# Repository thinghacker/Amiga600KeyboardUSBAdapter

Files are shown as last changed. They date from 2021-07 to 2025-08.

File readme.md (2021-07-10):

# Amiga600 Keyboard USB Adapter
This project enables an existing Amiga 600 Keyboard to operate as a USB Keyboard with the Case LEDs to indicate power/scroll lock and numlock.
This is a reimplementation of my previous [Teensy 2.0++ based PCB](https://github.com/thinghacker/amiga600_usb_pcb) and [QMK Firmware](https://github.com/thinghacker/qmk_firmware/tree/amiga600/keyboards/amiga600) adapter however as the Teensy 2.0++ is approaching end of sales availability and is relatively expensive,
this recreation uses the Raspberry Pi Pico in combination with a MCP20008 IO Expander for the keyboard interface and the keyboard driver software written in [CircuitPython](https://circuitpython.org/)

The [Kicad](https://www.kicad.org/) files used to create the PCB are in the [PCB-Amiga600Keyboard_USB_Pico](PCB-Amiga600Keyboard_USB_Pico/) directory - generated gerbers are the **plot** directory
The CircuitPython code is in the [CircuitPythonCode-Amiga600Keyboard_USB_Pico](CircuitPythonCode-Amiga600Keyboard_USB_Pico/) directory

Please note that the code requires the following libraries in addition to the base CircuitPython Install 
* [Adafruit_CircuitPython_HID](https://github.com/adafruit/Adafruit_CircuitPython_HID)
* [Adafruit_CircuitPython_MCP230xx](https://github.com/adafruit/Adafruit_CircuitPython_MCP230xx)

### Bill of Materials

|Designation | Item | Description | Manufacturer|
| --- | --- |--- | --- |
| U1 | Raspberry Pi Pico | RP2040 Board with USB Connector | https://www.raspberrypi.org/products/raspberry-pi-pico/ | 
| U2 | MCP20008 | 8 bit I2C IO Expander | https://www.microchip.com/wwwproducts/en/MCP23008 | 
|J1|4 Pin Header Right Angle PCB Mount 2.54mm spacing|Connects to Amiga 600 Case LEDs|Sullins Connector Solutions SWR25X-NRTC-S04-RB-BA available from Jaycar as HM3424|
|J2|30 Pin FPC Connector 1.25mm spacing| Connects to the Amiga 600 Keyboard Ribbon|Molex 39532304|
|R1 & R2 |4K7 Ohm Resistor|Pullups for I2C|various|

### PCB
This is a fairly simple two layer through hole design.  There are holes in the PCB to accomodate 3mm Nylon standoffs, self-adhesive types mean you can attach it to the back of the keyboard if desired.

Assembled Prototype PCB
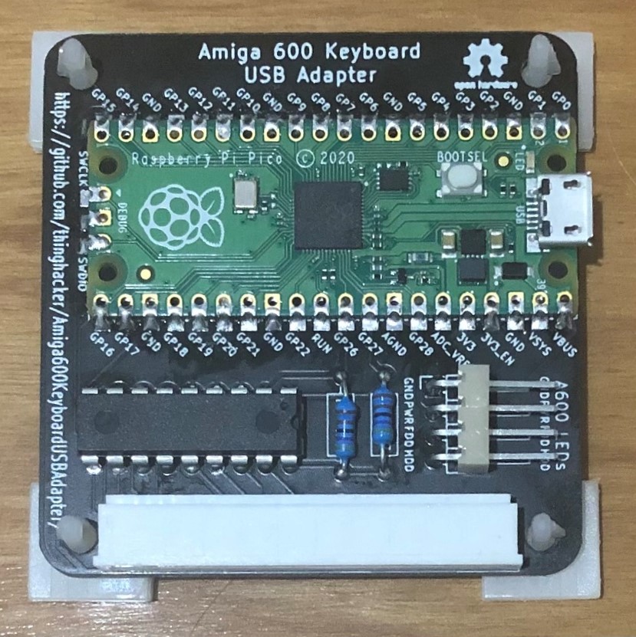
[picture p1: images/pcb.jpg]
Assembled Prototype PCB Image


Assembled Prototype PCB connected to a Keyboard
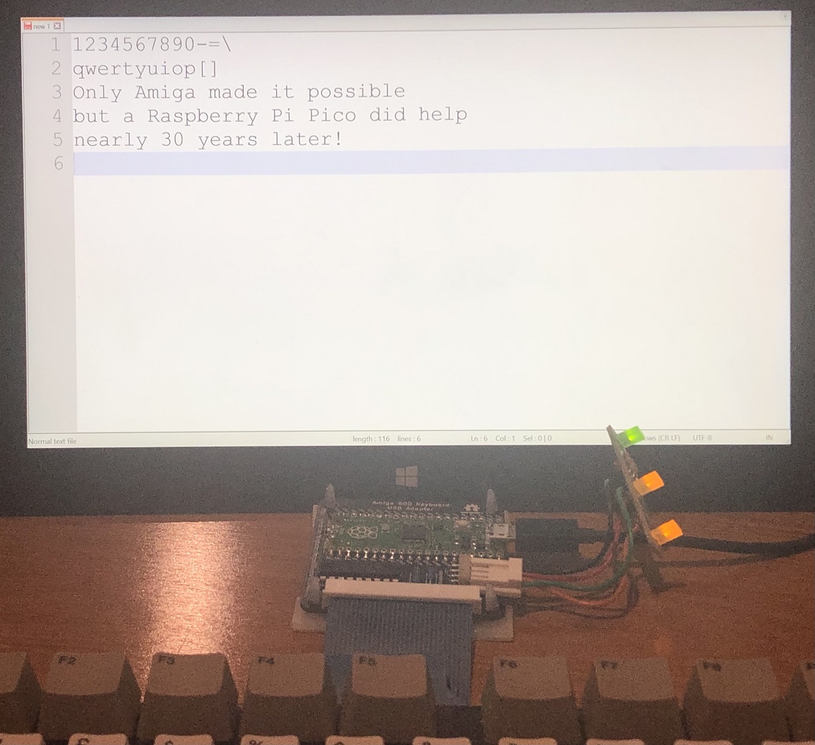
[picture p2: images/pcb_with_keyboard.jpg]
Assembled Prototype PCB Image


### Construction Notes
This PCB does not require any advanced soldering skills, it may be best to work with an experienced friend or watch some youtube videos on build techniques if you don't feel confident.

The hardware and software as written by me is distributed under a GPL Version 3 License

No claims to the name or any trademarks associated with Amiga, Raspberry Pi, Pico or Tim Tam are asserted here.

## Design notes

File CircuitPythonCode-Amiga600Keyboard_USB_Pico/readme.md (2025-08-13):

# Amiga600 Keyboard USB Adapter CircuitPython Firmware
This project enables an existing Amiga 600 Keyboard to be USB enabled via a Raspberry Pi Pico and MCP20008.

Keyboard Maintainer:  https://github.com/thinghacker

Supported Hardware: [Amiga 600 USB Keyboard Adapter](https://github.com/thinghacker/Amiga600KeyboardUSBAdapter/tree/main/PCB-Amiga600Keyboard_USB_Pico)

### Features

- Uses CircuitPython and two Adafruit Libraries
- Uses the Amiga 600 case LEDs for Power / Number Lock (FDD) and Scroll Lock (HDD)
- For the English keyboard variant, the two blank "International" keys shift layers to support more contemporary functions such as F11, F12, Numeric Keypad and Media Keys
- [Uses a simple PCB Design](https://github.com/thinghacker/Amiga600KeyboardUSBAdapter/tree/main/PCB-Amiga600Keyboard_USB_Pico) with a small number of components

### Build Instructions
- Construct the PCB and connect it to the USB port of your computer where the Pi Pico should appear as a USB flash drive
- Download the **uf2** file from [install CircuitPython](https://circuitpython.org/board/raspberry_pi_pico/) and copy it to your Pico Pico (this code was written using version 6.3.0)
- Copy the CircuitPython HID library [Adafruit_CircuitPython_HID](https://github.com/adafruit/Adafruit_CircuitPython_HID) (adafruit_hid directory) to the **lib** directory on your Pi Pico
- Copy the CircuitPython mcp230xx library [Adafruit_CircuitPython_MCP230xx](https://github.com/adafruit/Adafruit_CircuitPython_MCP230xx) (adafruit_mcp230xx directory) to the **lib** directory on your Pi Pico
- Copy the code.py file from this repo to your Pi Pico
- Remove the USB cable, attach the keyboard and LEDs to the Adapter
- Reattach the USB cable and type away!

### Keyboard Layer Configuration

#### Base Layer
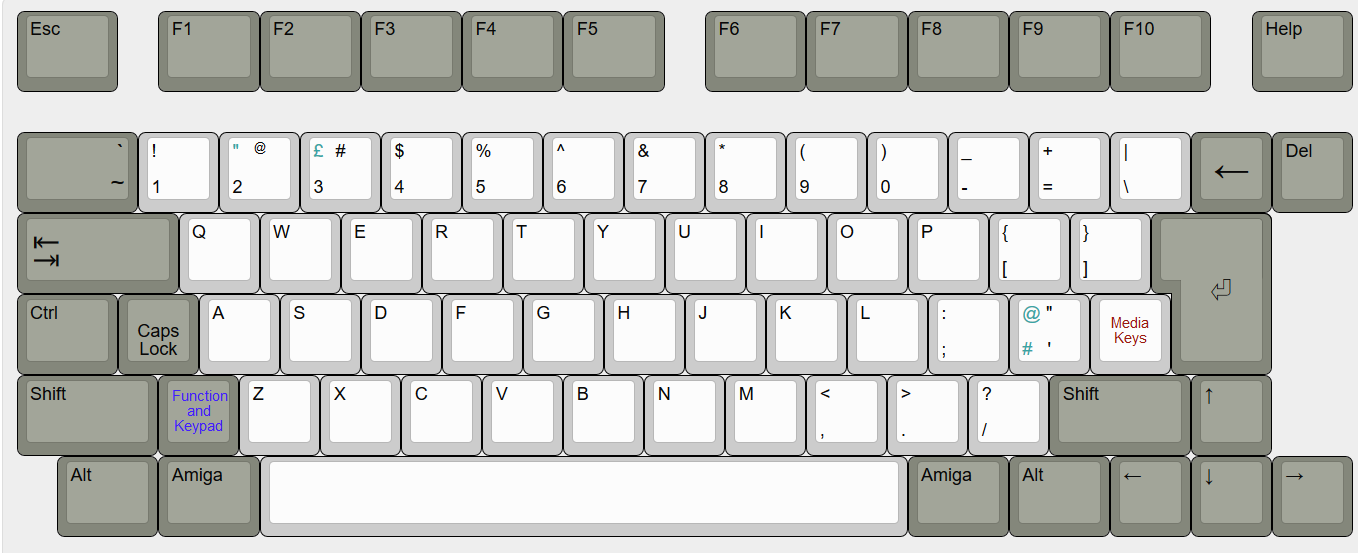
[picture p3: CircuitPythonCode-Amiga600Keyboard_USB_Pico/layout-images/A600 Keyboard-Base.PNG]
Base Layer


- My particular keyboard is the UK variant (differences are shown as Green on the keys), however this keymap is configured as if it was USA.
- The Left "Blank" Key (immediately to the right of left shift) is used to enable the Additional Function Keys and Numeric Keypad Layer
- The Right "Blank" Key (above right shift) is used to enable the Media Keys Layer

#### Additional Function Keys and Numeric Keypad Layer
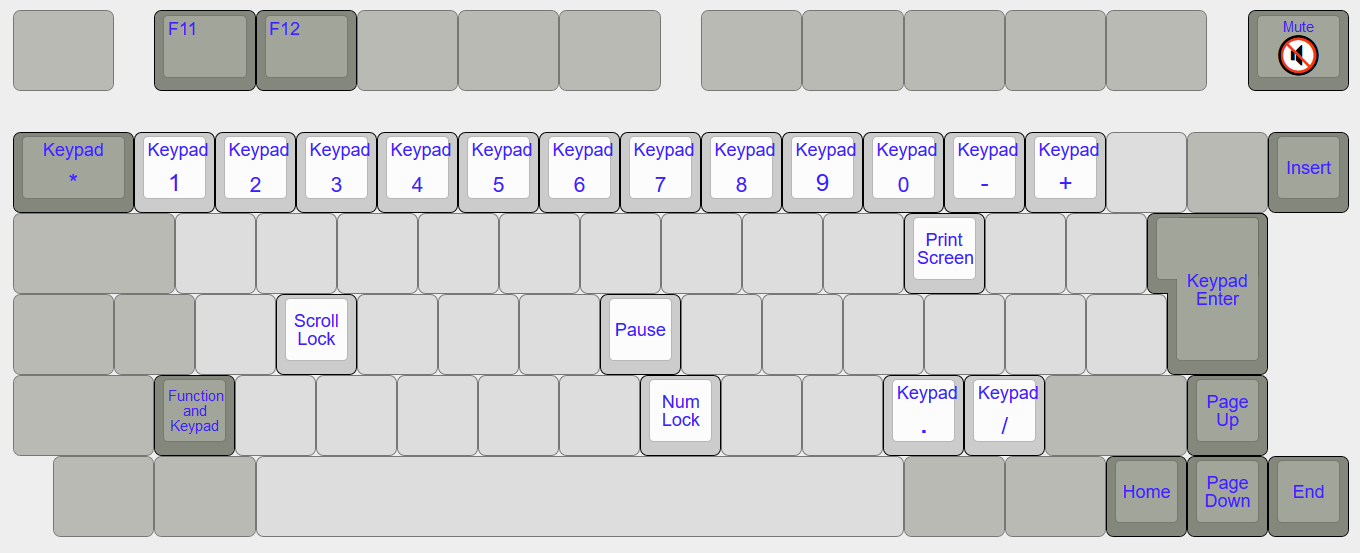
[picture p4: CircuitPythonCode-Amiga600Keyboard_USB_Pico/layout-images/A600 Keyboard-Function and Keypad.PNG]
Additional Function Keys and Numeric Keypad Layer


#### Media Keys Layer
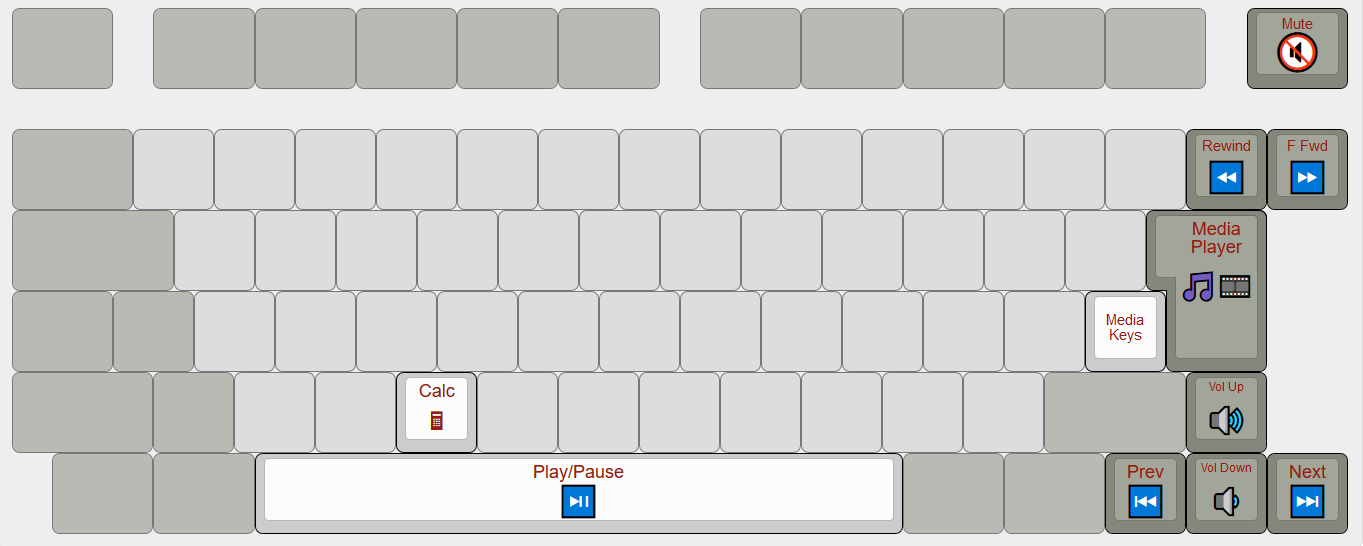
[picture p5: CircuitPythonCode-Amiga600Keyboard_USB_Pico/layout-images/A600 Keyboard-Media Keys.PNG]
Media Keys Layer


This is broadly inspired but very much a poor mans representation of the amazing [QMK firmware](https://github.com/qmk/qmk_firmware) that is extremely limited in scope and capability but seems good enough for me.

The software as written is distributed under a GPL Version 3 License

#### Update 14-Aug-2025
This project has not been actively maintained for some time, however thanks to [n0rt0nthec4t](https://github.com/n0rt0nthec4t) and [Amellinium](https://github.com/Amellinium) an [issue](https://github.com/thinghacker/Amiga600KeyboardUSBAdapter/issues/4) with regards to needing to remove and re-insert the keyboard has been addressed, thank you both for your help.

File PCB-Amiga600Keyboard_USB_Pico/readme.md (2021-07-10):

# Amiga600 Keyboard USB Adapter Using a Raspberry Pi Pico and MCP20008
This Kicad 5.1.10 project enables an existing Amiga 600 Keyboard to be USB enabled via a Raspberry Pi Pico and MCP20008 with the appropriate firmware such as [This CircuitPython Firmware](https://github.com/thinghacker/Amiga600KeyboardUSBAdapter/tree/main/CircuitPythonCode-Amiga600Keyboard_USB_Pico)

The hardware design open and distributed under a GPL Version 3 License

[Here is a PDF of the schematic for reference](schematic.pdf)

Gerbers have already been generated and are present in the "plot" directory

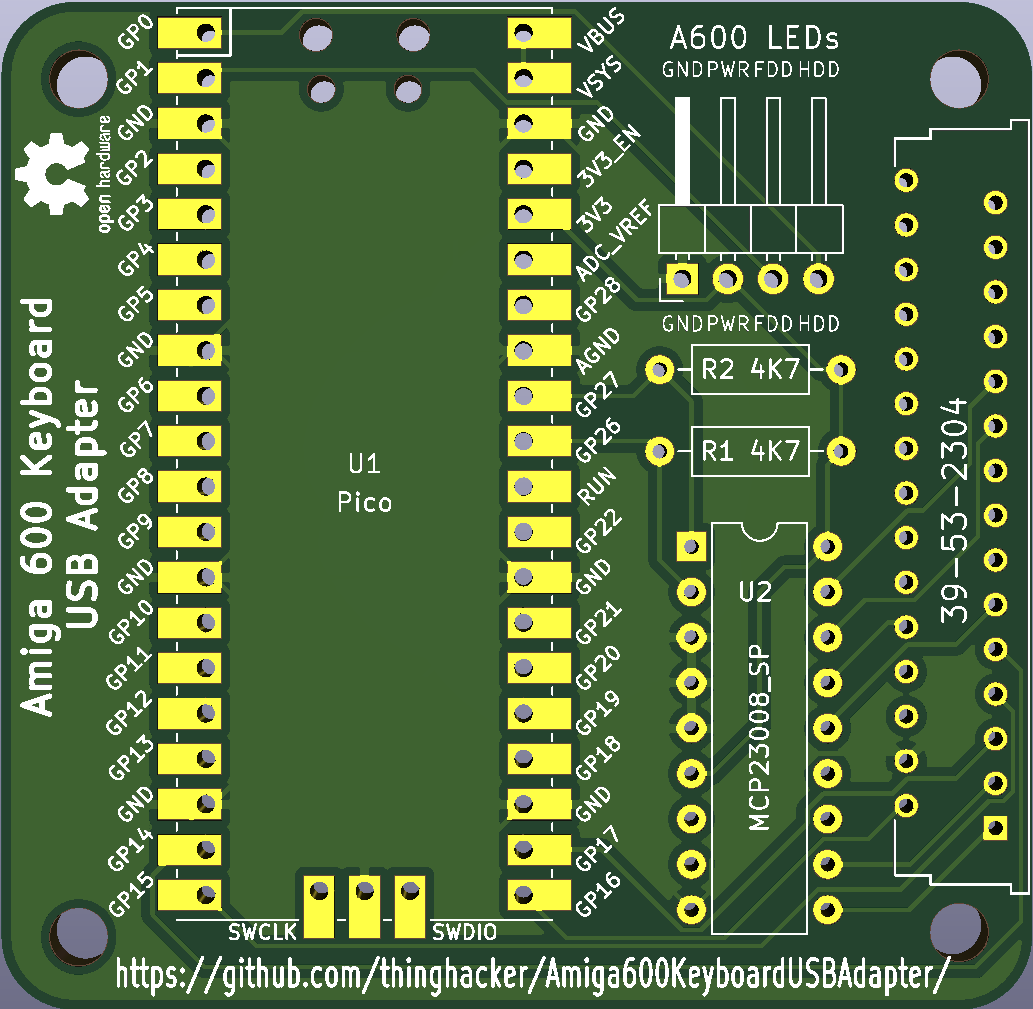
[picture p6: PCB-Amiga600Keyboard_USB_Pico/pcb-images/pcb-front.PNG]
PCB Front


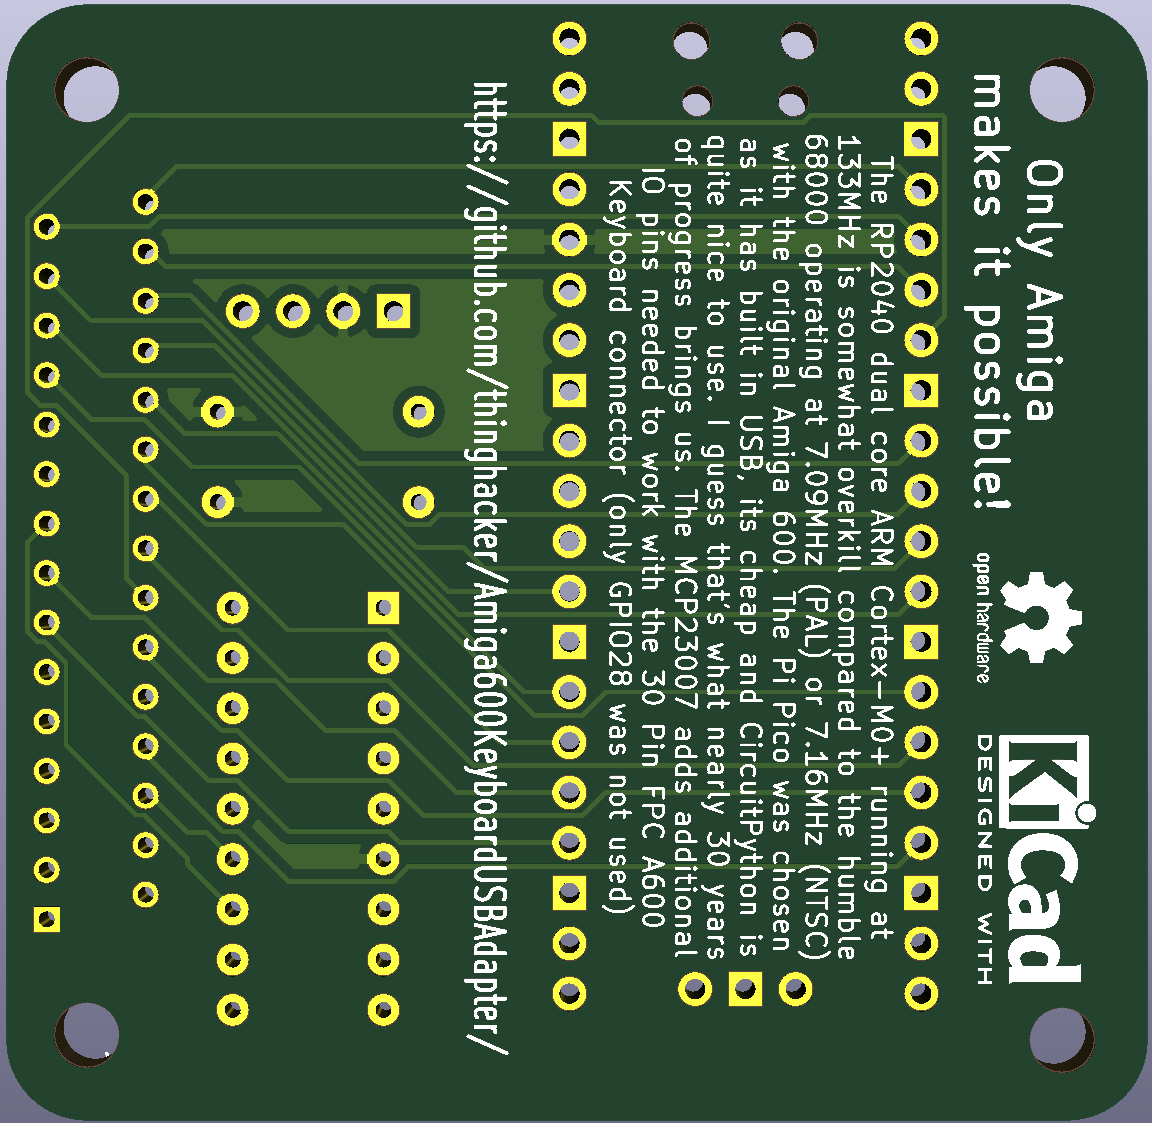
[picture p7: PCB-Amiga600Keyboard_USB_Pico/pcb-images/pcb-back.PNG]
PCB Back


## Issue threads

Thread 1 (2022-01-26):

Some suggestions for future improvements

OleUrgast, 2022-01-26:
Hello,

thanks for your great work.

I just got some mechanical keyboard PCBs (designed by Adam Eberbach [(aerberbach here on github](https://github.com/aeberbach/A600KB)) for the A600 from pcbway, as I want do make an Amiga emulator (Rasperry Pi, mechanical keyboard, DrawBridge with floppy, Slot-In CD-Drive).

Also I thought about how to make a keyboard controller and ordered some parts (Arduino Nano and CD74HC154EN). Than I found your project.

While I like your project a lot, I have a few questions:

- You use the two „blank“ keys for extra functions. As I am German, the two keycaps are not blank. How hard is it to change the function back to original keycode?

- I actually like extra keys. In the keyboard matrix the crosspoints 1/16, 1/22 and 1/24 are not used (the row with the function keys). I consider to glue the 3 LEDs onto little switches and let the LEDs become extra buttons, and wire them to 1/16, 1/22 and 1/24. So the look of the A600 does not change even with this „extra“ keys. How hard would it be to implement theese extra keys on 1/16, 1/22 and 1/24 into firmware?

Some suggestions:

You use nearly all of the I/Os of the Pi Pico + one extender IC. It seems a bit wastefull to me to use so much I/Os of the Pico, as only one colum of the Matrix is used at a time. As I thought about an own solution, I thought about a 4:16 decoder (CD74HC154EN). This Chip is quite simple: you connect it to 4 IO-Ports of the microcontroller, connect both enable inputs permanently to low. The 4 inputs are the „adress“ wich output is to be set to low. So if you set the 4 IOs to 0000, output 0 goes low, 0001, output 1 goes low,..., 1111 output 15 goes low. Always the other outputs are high.
So you can adress all 15 colums of the main keyboard matrix.
Also the reason for a seperate matrix for modifier only is anti-ghosting. Using a second 4:16 decoder (or a 3:8 one) on the same IOs would not result in ghosting, as the outputs still are seperated. So you can connect both 4:16 decoders to the same 4 I/Os. So for all the 22 colums you only need 4 I/Os of the Pico.

Only for the 6 rows (5 main matrix, 1 modifier matrix) you need one I/O per row to read wich key is pressed
So with 10 I/Os on the microcontroller you can actually read the complete keyboard (+1 I/O to light up caps-lock).
This gives you a lot of free I/Os on the Pi Pico and would allow aditional features.

Suggestions for additional features:

a) Joystick port. Actually Kerath v2 maps joysticks to the keymap. There are two methods most emulators support. Individual Computers (icomp.com) describes them on their website http://wiki.icomp.de/wiki/Keyrah_V2#Joystick_mapping.

b) A1200 keyboard support (extra 31 or 32 pin FCC connector (like used on aeberbachs A1200 mechanical keyboard))

c) Jumpers.
- Change configuration between maping extra functions to blank keys or send original keycode (international users) (mapping to 1/16, 1/22 and 1/24 can be always active in parallel, it does not hurt)
- Change between A600 and A1200 keyboard

d) extra output: Clock + Data for Amiga 1000/500/2000/3000/4000/CDTV/CD32 - so you can use your A600 Keyboard as an external keyboard for theese. Esp. if you add support for A1200 keyboards, this would allow mechanical keyboards using aeberbachs mechanical keyboards with your controller inside the original (keyboard-)case (exept on the A1000 of course). Of course level shifter is to be added due to Amiga using 5V

e) extra 4-pin connector for lines 1,16,22,24 to connect an external 3-key „keyboard“ (LEDs mounted on switches or extra keys hidden on the back of the Amiga case)

Just some ideas for further improvements in the future.

As I neither have skils in KiCad nor Python programing, I do not now if theese suggestions are possible to do or how hard it would be to implement them.

OleUrgast, 2022-02-01:
Actually even without Python knowlage your well written code seems to be easy to adapt to my needs.

For getting the international keycodes I found only "KEYPAD_BACKSLASH" wich should be one of the two blank keys on us-keyboards so far (it is marked "(non-us)" on https://circuitpython.readthedocs.io/projects/hid/en/latest/api.html ). I still not know the keycode for the other key, but as a full size keyboard US is 104 keys and ISO 105 keys the other key should exist in US layout also, so I will find it by trial and error. So I am pretty sure I only have to change KC.LAYERSHIFT_1 and KC.LAYERSHIFT_2 in KEYMAP_M1[0] to "KEYPAD_BACKSLASH" and the other code I still have to find out.

Also extra keys for function layer for international users are not needed, as there is a key most users do not like and deactivate anyway: Caps Lock. >95% the time Caps Lock is active, it was by accident. It is a relict from typewriters were the only way to emphesice something was to use capitals or underline a text. I know no one actual using capslock, even retro fans. There are people who deactivate it anyways, if they can. So all to get a function key for international users would be changing KC.CAPS_LOCK to KC.LAYERSHIFT_1 in KEYMAP_M1[0] if I understand correctly.

Even joystick emulation should be no problem, as there is still one free pin on the Pico (GPIO 28). So add it as an extra row after line 148 "digitalio.DigitalInOut(board.GP28)", connect it to the gnd pin of 9 pin d-sub sockets and wire pins 15,17,19,21,23 and 25 to up, down, left, right, fire1, fire2 of first joystick connector and pin 16,18,20,22,24 and 26 to up, down, left, right, fire1, fire2 of second joystick connector. Than add a line to KEYMAP_M1[...], so the coresponding numpad keycodes for emulators are send if joystick is used.

Practicly the 5/6 switches in a joystick are treated as extra keys (numpad keys) in a seperate row.

Of course this way only passive joysticks are supported, as we do not have real "ground" and neverever 5V for autofire joysticks (at least without using extra hardware). But autofire is cheating anyway and using some good old competition pro would definitly be a benefit.

All this should work without modifying the PCB, as the colums are easy to access at the back side of the PCB at the ribbon connector. Using every second pin means it is easy to solder standard pitch 2.54 pins (1*7, one not soldered to the connector but bend up and batchwired to GPIO28) to the back of the flat cable connector.

As soon as my PCBs arrive and get the controller board ready, I will definitly try this hack and report. If it works out as I think, you might add it into regular firmware, as adding a row to the matrix would'nt effect normal use at all. But maybe in future revisions of your board you might add two headers 1*7 (or even better: two 2*5 with one pin removed, to directly plug a db9 cable as used in older computers for serial conectors on a slot bracket. Would be nice to reuse theese old parts for joystick ports...)

thinghacker, 2022-02-01:
Hi, sorry for the delayed response but it is great that you are able to look at this and extend things to your liking, please let us know how it goes.

Regarding the keymapping - certainly the idea was that it should be possible adapt things to your own desires, for non-UK/US keyboards it should be possible modify things are necessary - in part I suspect it depends on how things are intended, if I understand https://usb.org/sites/default/files/hut1_21_0.pdf#page=83 correctly some of the changes should be transparent to a degree as the local USB host would determine the right re-mapping operation.
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
OleUrgast, 2022-02-12:
I made some progress - Not for the controller, as I still wait for the PCBs, but for the mechanical keyboard and the keycaps.

As I have a lot of plate-mounted switches flying around I got into problems to align them on the PCB. Without the two extra plasitic pins the 5-pin keys have, it is hard to solder them straight.
So I designed a mounting plate for the A600kb PCB. It also has holes to mount standard  chery-style stabilzers; as the keycap generator I use always place the mounting points same as on an 6.25u spacebars even if you make an 8.25u spacebar, this is quite usefull.

I added two photos, one from my first try with plate printed in two parts in my mk3s, the other improved one (more stiffness) printed on an Anycubic Predator in one piece.

Also I printed a (nearly) complete set of OEM Style keycaps. Only ISO-Enter in OEM Profile I am still looking for. As I am still learning how to print with resin, not all keycaps are perfect yet. But the last keycaps worked out quite well.
For the test I used green transparent resin, just because I got two liter with the printer. Sadly the A600kb from Adam has no backlightning, else I would bei tempted to use it for a Final Version (but using red transparent resin for the gray keycaps...). But maybe later I might do a version with handwired LEDs ...
I already have white and gray resin, but before using this, I will do some improvement on the spacebar, functionkeys and hopefully find an ISO-OEM enter. Also I will test dyesubbing in Resin first.

I will publish the mounting plate as soon as I fixed some minor issues in thingiverse. As I do not have an original Amiga 600 I so not know what changes might be needed to mount the keyboard with the plate inside.

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

OleUrgast, 2022-02-23:
Some progress:
- yesterday the PCBs for the controller arrived, so I will start my experiments this weekend
- Also reprinted some keycaps with 0.01mm layerhight. Great look, I also improved washing (prewasch in 1st tank, 10 min in wash&cure in a 2nd tank, and 20min in a 3d tank)
- I tryed finesanding (1000+2500+5000 paper) and polishing keycaps. Only the top, not the sides. It looks fantastic, but at the moment I need at least 5 minutes per normal key (about 25 min. if doing it on the sides also. Definitly nothing you want do for every keycap...). So a lot of work to do.
- tryed DyeSub for printing on keycaps. While I just improvised on tools (I used a simple iRon(TM)) and also I could only try with some old testprints (the waste ink container of the printer is full) on normal paper (not transfer paper) I saved from the bin, I can definitly tell: it works. The resin withstands the 200°C for the time needed. Just make sure to be careful with preasure (I cracked one key). On the green resin (it is more green and darker than on the picture) the contrast is less than optimal, esp. when keycap is polished. But as it definitly works, I will build a special tool to transfer on keycaps. On white and light gray resin keycaps it should definitly be a perfect solution to make cherry compatible Amiga 600 keycaps.
- I also made a Mechboard64 now. So I will try to adapt your controler for the 64keyboard also.
- Also I ordered the A1200kb (beside CapsLock LED being on the bottom instead of the top).
- As CapsLock will be used as FN, I think I will simply change Ctrl to become CapsLock in second layer. So CapsLock-Key + CTRL-Key pressed together will activate/deactivate CapsLock.

thinghacker, 2022-02-23:
Wow @OleUrgast , you have been making really good progress here,  Thanks again for keeping us updated with what you have been doing.

I am interested in your key printing technique, and from what I can see with your keycaps - it seems quite impressive and makes me want get a resin printer myself.

Nice work!

thinghacker, 2022-02-28:
@OleUrgast, you have started to inspire me to revisit this project,  I suspect the introduction of a 31pin connector to support Amiga 1200 keyboards as well as A600 would be pretty straight forward from a hardware standpoint (and the difference would mainly be the associated keymatrix), however I have been thinking a bit about legacy DB9 joystick/mouse connectivity you mentioned awhile back and have put something together as a starting point to understand creating gamepads using the Pi Pico - https://github.com/thinghacker/PiPicoUSBSegaController.

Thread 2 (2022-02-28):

Debug GND pin

bjorn-felle, 2022-02-28:
Thank you for this project :) I hope it's ok to post this question as an issue here. I'd like to build this using a Pi Pico breakout board so I can have the Pico socketed and use screw terminals to connect other components. None of the prefab breakout boards I have found have the debug pins connected. Is it essential to have the debug GND pin connected? I could solder on to this pin and then connect this on the breakout board to one of the GND screw terminals if necessary but I'd rather not modify the Pico unless it's absolutely necessary

thinghacker, 2022-02-28:
Hi, the front side of the PCB has a filled zone of which the ground pins (including the debug ground) is attached, so there should be requirement to connect this in your case.

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

bjorn-felle, 2022-02-28:
Thank you, that makes sense. I'll solder a wire to that pin on the Pico and then connect it to one of the spare GND pins on the screw terminal board. Thank you again, I'm excited to make this part of my A600 case mod :)

thinghacker, 2022-03-01:
@bjorn-felle - this is a bit embarrassing but I didn't include the NOT part in my response - you can leave the GND pin associated with debug free.  Sorry for the confusion, I hope this helps you with your mod.  The A600 seems to miss out on a lot of the love other Amigas tend to get!

bjorn-felle, 2022-03-01:
That's ok, I appreciate the replies! Just to be sure we're not at crossed purposes, I'm not going to make the PCB but will be breadboarding the circuit. So in this case I just leave the debug GND pin hanging and not connected to anything is that right? Sorry if this is the wrong place to discuss this by the way.

thinghacker, 2022-03-06:
Maybe you have already built it now but no, you do not need to connect the debug ground pin here

Closed 2022-03-01.

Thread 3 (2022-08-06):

Wrong behaviour

ingloriond, 2022-08-06:
579 / 5.000
First of all, thank you for this fantastic project. When I finished mounting the PCB and programming the picopi I connected it to the pc and it worked correctly with wordpad. However, after 1 minute a key started to stay pressed... the letter that remains pressed changes. I thought maybe there was some flaw in the welds or even the picopi. Mount another new PCB, just only reuse the 8-bit I2C IO expander. The result has been the same... It works and after a short time it starts writing by itself. The keyboard works fine on an A600
Any suggestion?
Thank you

thinghacker, 2022-08-23:
Sorry for the delayed response. My keyboard/circuit is in storage at the moment but I will aim to bring it out and re-run things to see if I can replicate the condition you describe and track it from there.

As a matter of interest, is it the same key that is appearing to stay in a down state each time or is it different?  When the condition occurs - if you unplug the USB and re-insert it, do things work normally again?  If not, if you leave it power down for a period of time does does it work as expected for a period of time?  Without being in a position to re-run things right now, I am just trying to see if there is anything mechanical/thermal related., alternatively it may be worth increasing the delay timer in line 97 (currently 0.01) to a higher value and see if that improves the situation.

ingloriond, 2022-08-27:
Don't worry.. I've got it in a storage right now too. No, is going worse... sometimes didnt write any letters and especial funtions were active by default.. Sometimes if i conect to pc, my mouse always have right button pushed... too strange ¿maybe can be 8 bit I2C IO Expander?Is the only  thing I reuse from first pcb

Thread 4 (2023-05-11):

Boot issue when attached to RPI4

n0rt0nthec4t, 2023-05-11:
Firstly, thank you for creating this project. I've just built this to replace my KeyRah v2 which using for a "Amiga PI" inside an A600 case.. Just need some more space inside and this project gave me that,

I have a weird issue when having this attached to my RPI4, in that the keyboard doesnt work on first boot. Need to disconnect the USB cable and reconnect, then all works.

Any suggestions on how to trace this down to a solution?

n0rt0nthec4t, 2023-05-11:
Also suggest it is a good idea to have a boot.py file with the follow contents to disable USB midi and serial

```
import usb_midi
import usb_cdc

usb_cdc.disable()   # Disable both serial devices.
usb_midi.disable()  # Disable mini
````

Amellinium, 2025-08-12:
Hi, I’ve updated the Pico to CircuitPython 9.2.8 and also updated the libraries.

Libraries used in the lib folder:
adafruit_bus_device
adafruit_hid
adafruit_mcp230xx
adafruit_register

**boot.py**
```
import usb_midi
import usb_cdc
import usb_hid

usb_cdc.disable()   # Disable both serial devices
usb_midi.disable()  # Disable MIDI
usb_hid.enable((usb_hid.Device.KEYBOARD, usb_hid.Device.CONSUMER_CONTROL))
```

**Added to the start of code.py:**
```
import time
time.sleep(0.5)
```

thinghacker, 2025-08-13:
Thanks very much - I have inserted the changes from yourself and n0rt0nthec4t, thanks for sharing the fixes

Closed 2025-08-13.

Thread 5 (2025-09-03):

Potential usbhid issue on Ubuntu

medavidallsop, 2025-09-03:
Hi,

I’m using this adapter which I got from eBay, on an ACEMAGIC Vista Mini V1 running Ubuntu 24.04.3 LTS.

Occasionally the whole system freezes completely, only hard power-off helps.

I see this in the logs after reboot:

usbhid 1-6:1.3: couldn't find an input interrupt endpoint

Ran this through AI and it suggests:

It looks like the adapter’s USB HID descriptors might not be fully compatible with the Linux HID driver. Could this be a firmware bug, or is there a known workaround (e.g., updated firmware, quirks setting, etc.)

I have no idea if this error is related to this device, and I don't really have any experience with this sorta thing, but if this is related could you help with any things I can try to fix it.

Thanks!

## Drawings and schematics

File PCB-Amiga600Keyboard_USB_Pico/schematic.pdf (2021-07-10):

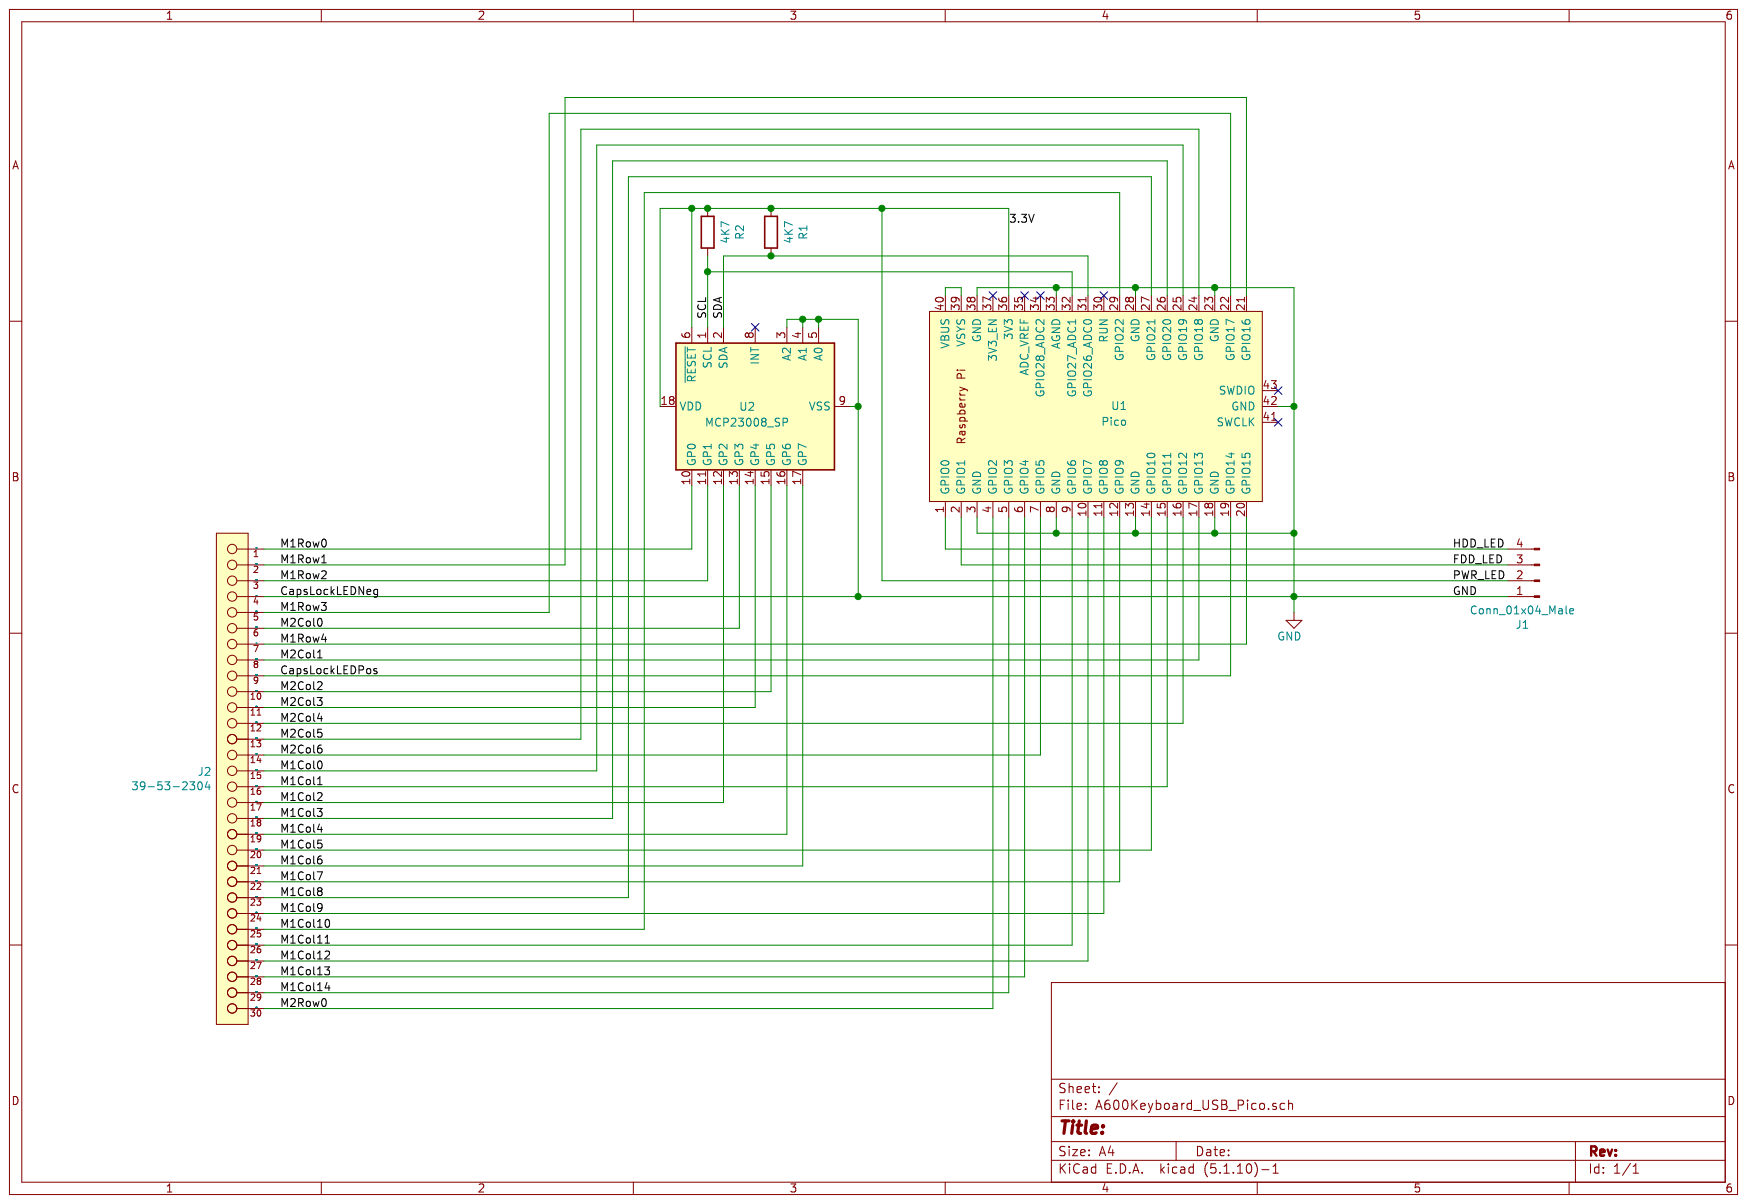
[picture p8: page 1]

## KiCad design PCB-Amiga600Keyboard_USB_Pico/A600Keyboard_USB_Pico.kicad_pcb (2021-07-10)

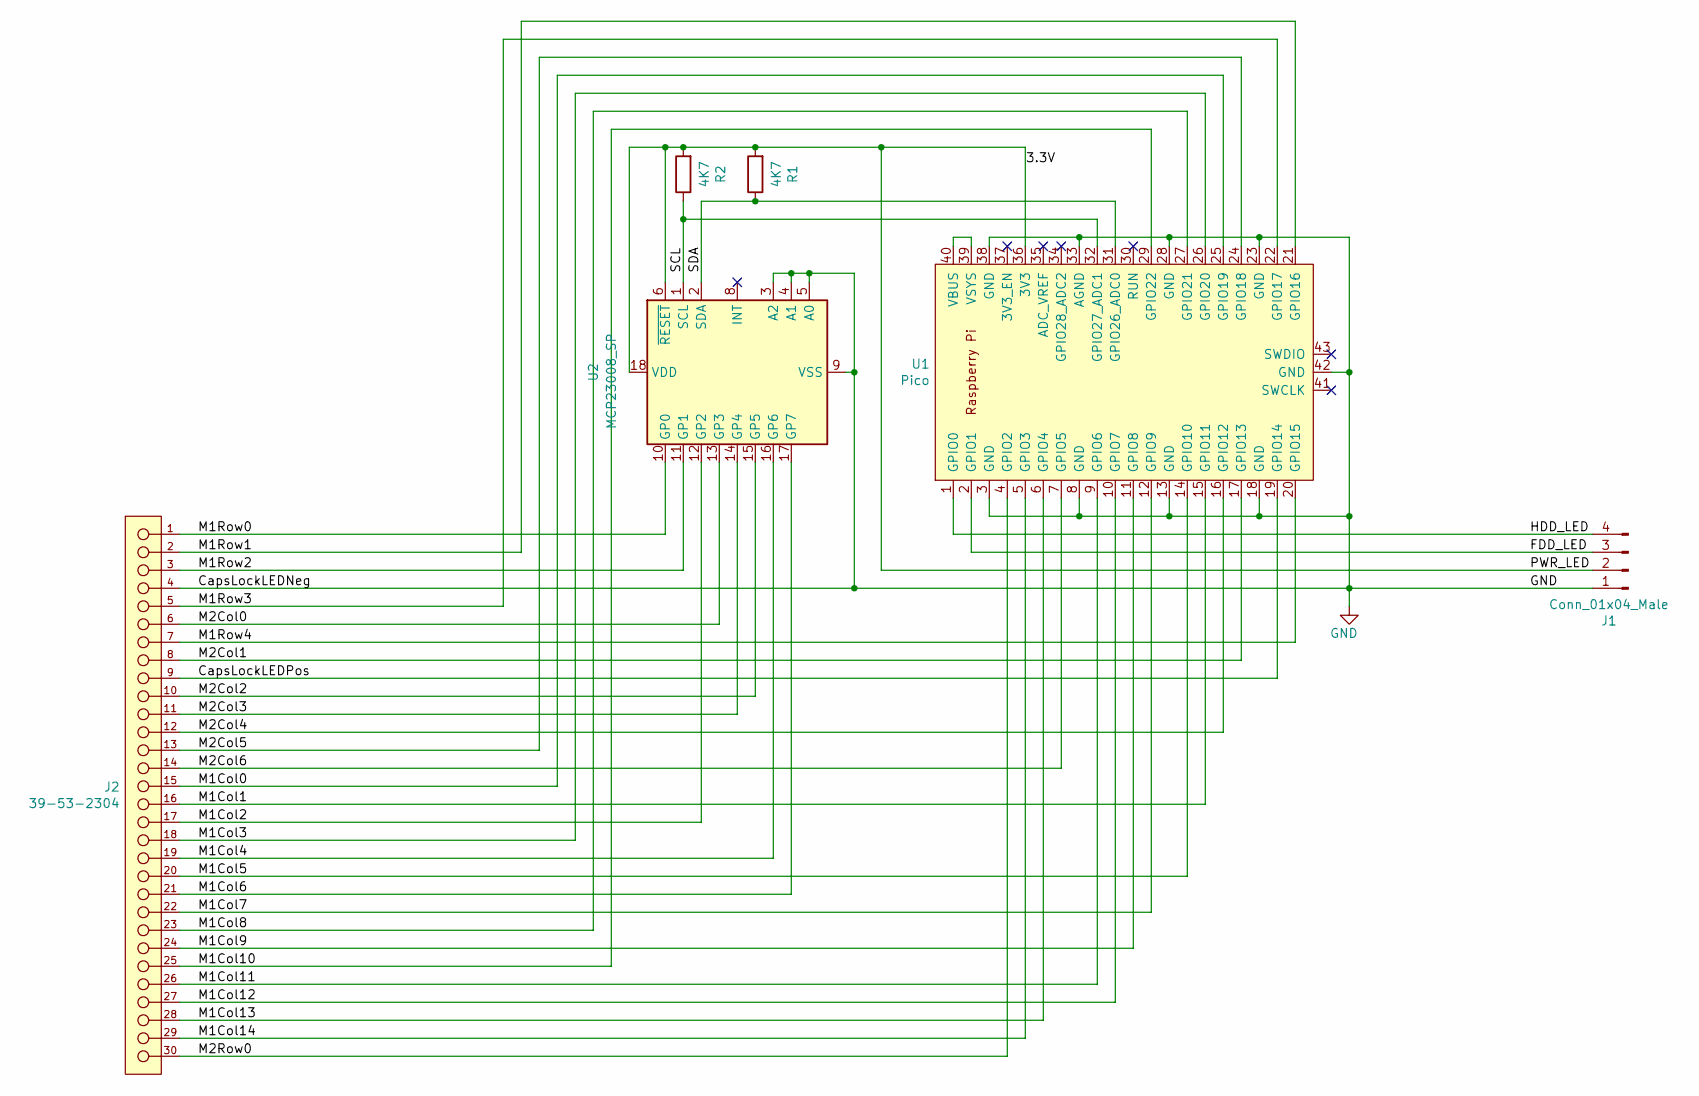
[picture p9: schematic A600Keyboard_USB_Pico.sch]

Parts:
J1: Conn_01x04_Male; PinHeader_1x04_P2.54mm_Horizontal
J2: 39-53-2304; Molex-39-53-2304-Manufacturer_Recommended; Voltage Max 200V
R1, R2: 4K7; R_Axial_DIN0207_L6.3mm_D2.5mm_P10.16mm_Horizontal
U1: Pico; RPi_Pico_SMD_TH
U2: MCP23008_SP; DIP-18_W7.62mm

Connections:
/3.3V: J1.2, R1.2, R2.2, U1.36 (3V3), U2.6 (~RESET), U2.18 (VDD)
/CapsLockLEDPos: J2.9, U1.19 (GPIO14)
/FDD_LED: J1.3, U1.2 (GPIO1)
/HDD_LED: J1.4, U1.1 (GPIO0)
/M1Col0: J2.15, U1.25 (GPIO19)
/M1Col1: J2.16, U1.15 (GPIO11)
/M1Col2: J2.17, U2.12 (GP2)
/M1Col3: J2.18, U1.26 (GPIO20)
/M1Col4: J2.19, U2.16 (GP6)
/M1Col5: J2.20, U1.14 (GPIO10)
/M1Col6: J2.21, U2.17 (GP7)
/M1Col7: J2.22, U1.12 (GPIO9)
/M1Col8: J2.23, U1.27 (GPIO21)
/M1Col9: J2.24, U1.11 (GPIO8)
/M1Col10: J2.25, U1.29 (GPIO22)
/M1Col11: J2.26, U1.9 (GPIO6)
/M1Col12: J2.27, U1.10 (GPIO7)
/M1Col13: J2.28, U1.6 (GPIO4)
/M1Col14: J2.29, U1.5 (GPIO3)
/M1Row0: J2.1, U2.10 (GP0)
/M1Row1: J2.2, U1.21 (GPIO16)
/M1Row2: J2.3, U2.11 (GP1)
/M1Row3: J2.5, U1.22 (GPIO17)
/M1Row4: J2.7, U1.20 (GPIO15)
/M2Col0: J2.6, U2.13 (GP3)
/M2Col1: J2.8, U1.17 (GPIO13)
/M2Col2: J2.10, U2.15 (GP5)
/M2Col3: J2.11, U2.14 (GP4)
/M2Col4: J2.12, U1.16 (GPIO12)
/M2Col5: J2.13, U1.24 (GPIO18)
/M2Col6: J2.14, U1.7 (GPIO5)
/M2Row0: J2.30, U1.4 (GPIO2)
/SCL: R2.1, U1.32 (GPIO27_ADC1), U2.1 (SCL)
/SDA: R1.1, U1.31 (GPIO26_ADC0), U2.2 (SDA)
GND: J1.1, J2.4, U1.3 (GND), U1.8 (GND), U1.13 (GND), U1.18 (GND), U1.23 (GND), U1.28 (GND), U1.33 (AGND), U1.38 (GND), U1.42 (GND), U2.3 (A2), U2.4 (A1), U2.5 (A0), U2.9 (VSS)
unnamed: U1.39 (VSYS), U1.40 (VBUS)

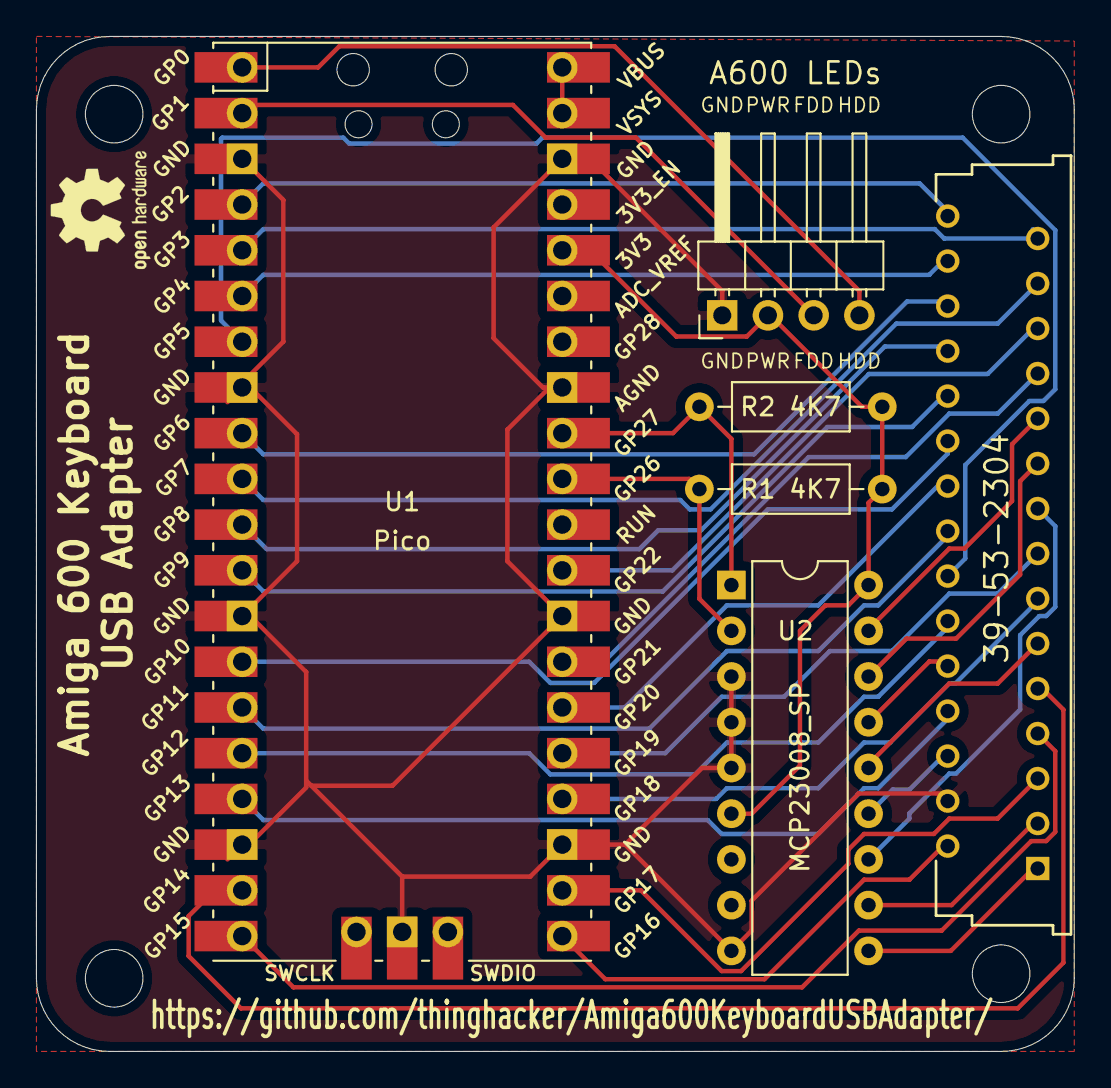
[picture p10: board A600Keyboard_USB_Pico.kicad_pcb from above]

Board: 2 copper layers, 57.7 x 56.4 mm, 6 parts (0 on the bottom side), 36 nets.

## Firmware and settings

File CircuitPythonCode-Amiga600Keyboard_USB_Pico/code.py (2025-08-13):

import time
# initial delay to avoid needing to unplug/replug in some instances for keyboard detection
time.sleep(0.5)

import usb_hid
import board
import digitalio
from adafruit_hid.keyboard import Keyboard
from adafruit_hid.keycode import Keycode
from adafruit_hid.consumer_control import ConsumerControl
from adafruit_hid.consumer_control_code import ConsumerControlCode

import board
import busio
from adafruit_mcp230xx.mcp23008 import MCP23008

i2c = busio.I2C(scl=board.GP27, sda=board.GP26)
mcp = MCP23008(i2c)  # MCP23008

# Initialize consumer control
cc = ConsumerControl(usb_hid.devices)

# Initialize Keyboard
kbd = Keyboard(usb_hid.devices)

leds = {
    "onboard": digitalio.DigitalInOut(board.LED),
    "caplock": digitalio.DigitalInOut(board.GP14),
    "fdd": digitalio.DigitalInOut(board.GP1),
    "hdd": digitalio.DigitalInOut(board.GP0),
}

for led, pinio in leds.items():
    pinio.direction = digitalio.Direction.OUTPUT

class key:
 def __init__(self, keycode, value, type):
  self.keycode = keycode
  self.value = value
  self.type = type
 def keypress(self):
  if self.type == "hidkb":
   kbd.press(self.value)
  elif self.type == "consumercontrol":
   cc.send(self.value)
 def keyrelease(self):
  if self.type == "hidkb":
   kbd.release(self.value)

class keyboard:
 def __init__(self):
  # use adafruit_hid.keycodes
  self.__keycodes = { kc: getattr(Keycode, kc) for kc in dir(Keycode) if not kc.startswith('__') and not callable(getattr(Keycode, kc)) }
  for (k,v) in self.__keycodes.items():
    setattr(self, k, key(k, v, "hidkb"))
  # use adafruit_hid.consumer_control_codes
  self.__consumercontrolcodes = {c: getattr(ConsumerControlCode, c) for c in dir(ConsumerControlCode) if not c.startswith('__') and not callable(getattr(ConsumerControlCode, c)) }
  # lots of consumer control codes are not in adafruit library but we can add https://www.usb.org/sites/default/files/hut1_21_0.pdf#page=123.
  self.__additionalconsumercontrolcodes = { "CALC": 0x192 }
  self.__consumercontrolcodes.update(self.__additionalconsumercontrolcodes)
  for (k,v) in self.__consumercontrolcodes.items():
    setattr(self, k, key(k, v, "consumercontrol"))
  self.__layershiftcodes = { "LAYERSHIFT_0": 0, "LAYERSHIFT_1": 1, "LAYERSHIFT_2": 2 }
  for (k,v) in self.__layershiftcodes.items():
    setattr(self, k, key(k, v, "layershift"))

KC = keyboard()

def initmatrix(rows, cols):
    """initmatrix

    Set the pins in array rows as output and with value high
    Set the pins in array cols as input and with pullups enabled

    returns nothing
    """
    for row in rows:
        row.direction = digitalio.Direction.OUTPUT
        row.value = True
    for column in cols:
        column.direction = digitalio.Direction.INPUT
        column.pull = digitalio.Pull.UP


def scanmatrix(rows, cols):
    """scanmatrix

    Incrementally set each row pin to low and see if a col pin is pulled low
    False indicates that a key is pressed, True key not pressed

    returns a matrix of rows and cols
    """
    matrix = []
    for row, r in enumerate(rows):
        rows[row].value = False
        for column, c in enumerate(cols):
            matrix.append(cols[column].value)
        rows[row].value = True
        time.sleep(0.01)
    return matrix


def keystatechange(matrix, oldmatrix, KEYMAP, LAYER):
    """keystatechange

    compares the current matrix (matrix) with the previous (oldmatrix) to see if there are
    any key changes or not

    If they are, consider the active keymap via Layer and determine if a key press, release
    or layer change should occur

    returns NEWLAYER
    """

    NEWLAYER = LAYER
    if matrix != oldmatrix:
      for k, v in enumerate(matrix):
        if matrix[k] != oldmatrix[k] and KEYMAP[LAYER][k] != None:
           # False if Key is pressed
           if matrix[k] is False:
               if KEYMAP[LAYER][k].type == "layershift":
                 NEWLAYER = KEYMAP[LAYER][k].value
               KEYMAP[LAYER][k].keypress()
           # True if Key is released
           elif matrix[k] is True:
               if KEYMAP[LAYER][k].type == "layershift":
                 NEWLAYER = 0
               KEYMAP[LAYER][k].keyrelease()
    return NEWLAYER

def a600keyboard():
    """a600keyboard

    Initialize system to use two keyboard matrices KEYMAP_M1 and KEYMAP_M2
    that combined represent the entire A600 keyboard

    Keyboard state changes are read and sent as USB HID messages to the host computer

    HID reports from the computer with regard to CAPS_LOCK, SCROLL_LOCK and NUM_LOCK
    for setting LED states

    The main while state loop will forever
    """

    rows1 = [
        mcp.get_pin(0),
        digitalio.DigitalInOut(board.GP16),
        mcp.get_pin(1),
        digitalio.DigitalInOut(board.GP17),
        digitalio.DigitalInOut(board.GP15),
    ]
    cols1 = [
        digitalio.DigitalInOut(board.GP19),
        digitalio.DigitalInOut(board.GP11),
        mcp.get_pin(2),
        digitalio.DigitalInOut(board.GP20),
        mcp.get_pin(6),
        digitalio.DigitalInOut(board.GP10),
        mcp.get_pin(7),
        digitalio.DigitalInOut(board.GP9),
        digitalio.DigitalInOut(board.GP21),
        digitalio.DigitalInOut(board.GP8),
        digitalio.DigitalInOut(board.GP22),
        digitalio.DigitalInOut(board.GP6),
        digitalio.DigitalInOut(board.GP7),
        digitalio.DigitalInOut(board.GP4),
        digitalio.DigitalInOut(board.GP3),
    ]
    rows2 = [digitalio.DigitalInOut(board.GP2)]
    cols2 = [
        mcp.get_pin(3),
        digitalio.DigitalInOut(board.GP13),
        mcp.get_pin(5),
        mcp.get_pin(4),
        digitalio.DigitalInOut(board.GP12),
        digitalio.DigitalInOut(board.GP18),
        digitalio.DigitalInOut(board.GP5),
    ]

    # Initialize the matrix row and col pins
    initmatrix(rows1, cols1)
    initmatrix(rows2, cols2)

    # Initialize the old matrix values
    oldmatrix1 = [True] * (len(rows1) * len(cols1))
    oldmatrix2 = [True] * (len(rows2) * len(cols2))

    # Each Keymap matrix has 3 layers (layer 0 is the normal/default)
    KEYMAP_M1 = ["LAYER0","LAYER1","LAYER2"]
    KEYMAP_M2 = ["LAYER0","LAYER1","LAYER2"]

    # Based on http://www.amigawiki.org/dnl/schematics/A600_R1.5.pdf (last page)
    # When LAYER = 0
    KEYMAP_M1[0] = [ KC.ESCAPE,          None,          KC.F1,         KC.F2,           KC.F3,          KC.F4,          KC.F5,            None,            KC.F6,           None,            KC.F7,                  KC.F8,           KC.F9,            KC.F10,              KC.F1,
                     KC.GRAVE_ACCENT,    KC.ONE,        KC.TWO,        KC.THREE,        KC.FOUR,        KC.FIVE,        KC.SIX,           KC.SEVEN,        KC.EIGHT,        KC.NINE,         KC.ZERO,                KC.MINUS,        KC.EQUALS,        KC.BACKSLASH,        KC.UP_ARROW,
                     KC.TAB,             KC.Q,          KC.W,          KC.E,            KC.R,           KC.T,           KC.Y,             KC.U,            KC.I,            KC.O,            KC.P,                   KC.LEFT_BRACKET, KC.RIGHT_BRACKET, KC.RETURN,           KC.LEFT_ARROW,
                     KC.CAPS_LOCK,       KC.A,          KC.S,          KC.D,            KC.F,           KC.G,           KC.H,             KC.J,            KC.K,            KC.L,            KC.SEMICOLON ,          KC.QUOTE,        KC.LAYERSHIFT_1,  KC.DELETE,           KC.RIGHT_ARROW,
                     KC.LAYERSHIFT_2,    KC.Z,          KC.X,          KC.C,            KC.V,           KC.B,           KC.N,             KC.M,            KC.COMMA,        KC.PERIOD,       KC.FORWARD_SLASH,       None,            KC.SPACE,         KC.BACKSPACE,        KC.DOWN_ARROW ]
    KEYMAP_M2[0] = [ KC.RIGHT_SHIFT,     KC.RIGHT_ALT,  KC.RIGHT_GUI,  KC.CONTROL,      KC.LEFT_SHIFT,  KC.LEFT_ALT,    KC.LEFT_GUI]

    # When LAYER = 1
    KEYMAP_M1[1] = [ None,               None,          KC.F11,        KC.F12,          None,           None,           None,             None,            None,            None,            None,                   None,            None,             None,                KC.MUTE,
                     KC.KEYPAD_ASTERISK, KC.KEYPAD_ONE, KC.KEYPAD_TWO, KC.KEYPAD_THREE, KC.KEYPAD_FOUR, KC.KEYPAD_FIVE, KC.KEYPAD_SIX,    KC.KEYPAD_SEVEN, KC.KEYPAD_EIGHT, KC.KEYPAD_NINE,  KC.KEYPAD_ZERO,         KC.KEYPAD_MINUS, KC.KEYPAD_PLUS,   KC.KEYPAD_BACKSLASH, KC.PAGE_UP,
                     None,               None,          None,          None,            None,           None,           None,             None,            None,            None,            KC.PRINT_SCREEN,        None,            None,             KC.KEYPAD_ENTER,     KC.HOME,
                     None,               None,          KC.SCROLL_LOCK,None,            None,           None,           KC.PAUSE,         None,            None,            None,            None,                   None,            KC.LAYERSHIFT_0,     None,                KC.END,
                     None,               None,          None,          None,            None,           None,           KC.KEYPAD_NUMLOCK,None,            None,            KC.KEYPAD_PERIOD,KC.KEYPAD_FORWARD_SLASH,None,            None,             None,                KC.PAGE_DOWN ]
    KEYMAP_M2[1] = [ None,               None,          None,          None,            None,           None,           None       ]

    # When LAYER = 2
    KEYMAP_M1[2] = [ None,               None,          None,          None,            None,           None,           None,             None,            None,            None,            None,                   None,            None,             None,                KC.MUTE,
                     None,               None,          None,          None,            None,           None,           None,             None,            None,            None,            None,                   None,            None,             None,                KC.VOLUME_INCREMENT,
                     None,               None,          None,          None,            None,           None,           None,             None,            None,            None,            None,                   None,            None,             KC.STOP,             KC.SCAN_PREVIOUS_TRACK,
                     None,               None,          None,          None,            None,           None,           None,             None,            None,            None,            None,                   None,            None,             None,                KC.SCAN_NEXT_TRACK,
                     KC.LAYERSHIFT_0,    None,          None,          KC.CALC,         None,           None,           None,             None,            None,            None,            None,                   None,            KC.PLAY_PAUSE,    None,                KC.VOLUME_DECREMENT ]
    KEYMAP_M2[2] = [ None,               None,          None,          None,            None,           None,           None       ]

    LAYER = 0

    kbd.release_all()

    # Main Keyboard Loop
    while 1:
        matrix1 = scanmatrix(rows1, cols1)
        LAYER = keystatechange(matrix1, oldmatrix1, KEYMAP_M1, LAYER)

        matrix2 = scanmatrix(rows2, cols2)
        LAYER = keystatechange(matrix2, oldmatrix2, KEYMAP_M2, LAYER)

        oldmatrix1 = matrix1
        oldmatrix2 = matrix2

        leds["caplock"].value = kbd.led_on(Keyboard.LED_CAPS_LOCK)
        leds["fdd"].value = kbd.led_on(Keyboard.LED_NUM_LOCK)
        leds["hdd"].value = kbd.led_on(Keyboard.LED_SCROLL_LOCK)


if __name__ == "__main__":
    a600keyboard()

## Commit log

2021-07-09 First Release
    [A600Keyboard_USB_Pico-B_Cu.gbr, A600Keyboard_USB_Pico-B_Mask.gbr, A600Keyboard_USB_Pico-B_SilkS.gbr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]
2021-07-10 Back Silk Screen Correction
    [A600Keyboard_USB_Pico.kicad_pcb]
2025-08-13 Update code.py - initial delay to avoid initial detection problem
    Fix provided by Amellinium 12-Aug-25
    [code.py]
